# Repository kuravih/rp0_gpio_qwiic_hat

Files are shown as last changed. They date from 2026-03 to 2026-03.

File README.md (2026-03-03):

# Raspberry Pi qwiic hat

Raspberry pi GPIO pins can can be configured as i<sup>2</sup>c as described [here][1].
There are 28 GPIO pins which can be configured as 14 i<sup>2</sup>c buses in total.
This hat wires these 14 i<sup>2</sup>c busses including the [5 V rail][3] and the ground to 14 [qwiic][2] connectors.
Add the following to the `[all]` section of the `/boot/firmware/config.txt` file to enable the i<sup>2</sup>c busses.
The i<sup>2</sup>c devices will be available at `dev/i2c-n` (where n will be the bus number used in the dtoverlay).
This setup along with ~100 [ds28ea00_sensorlets][4] were flown on PICTURE-C flight in 2025 to continuously monitor the instrument temperature at numerous locations.

    dtoverlay=i2c-gpio,i2c_gpio_sda=27,i2c_gpio_scl=18,bus=10
    dtoverlay=i2c-gpio,i2c_gpio_sda=25,i2c_gpio_scl=9,bus=11
    dtoverlay=i2c-gpio,i2c_gpio_sda=5,i2c_gpio_scl=11,bus=12
    dtoverlay=i2c-gpio,i2c_gpio_sda=12,i2c_gpio_scl=6,bus=13
    dtoverlay=i2c-gpio,i2c_gpio_sda=19,i2c_gpio_scl=26,bus=14
    dtoverlay=i2c-gpio,i2c_gpio_sda=15,i2c_gpio_scl=17,bus=15
    dtoverlay=i2c-gpio,i2c_gpio_sda=23,i2c_gpio_scl=22,bus=16
    dtoverlay=i2c-gpio,i2c_gpio_sda=10,i2c_gpio_scl=24,bus=17
    dtoverlay=i2c-gpio,i2c_gpio_sda=1,i2c_gpio_scl=0,bus=18
    dtoverlay=i2c-gpio,i2c_gpio_sda=2,i2c_gpio_scl=3,bus=19
    dtoverlay=i2c-gpio,i2c_gpio_sda=4,i2c_gpio_scl=14,bus=20
    dtoverlay=i2c-gpio,i2c_gpio_sda=7,i2c_gpio_scl=8,bus=21
    dtoverlay=i2c-gpio,i2c_gpio_sda=20,i2c_gpio_scl=21,bus=22
    dtoverlay=i2c-gpio,i2c_gpio_sda=16,i2c_gpio_scl=13,bus=23

## Schematic
<p align="center">
  Schematic
</p>

## PCB

<p align="center">
  PCB
</p>

## Photos

<p align="center">
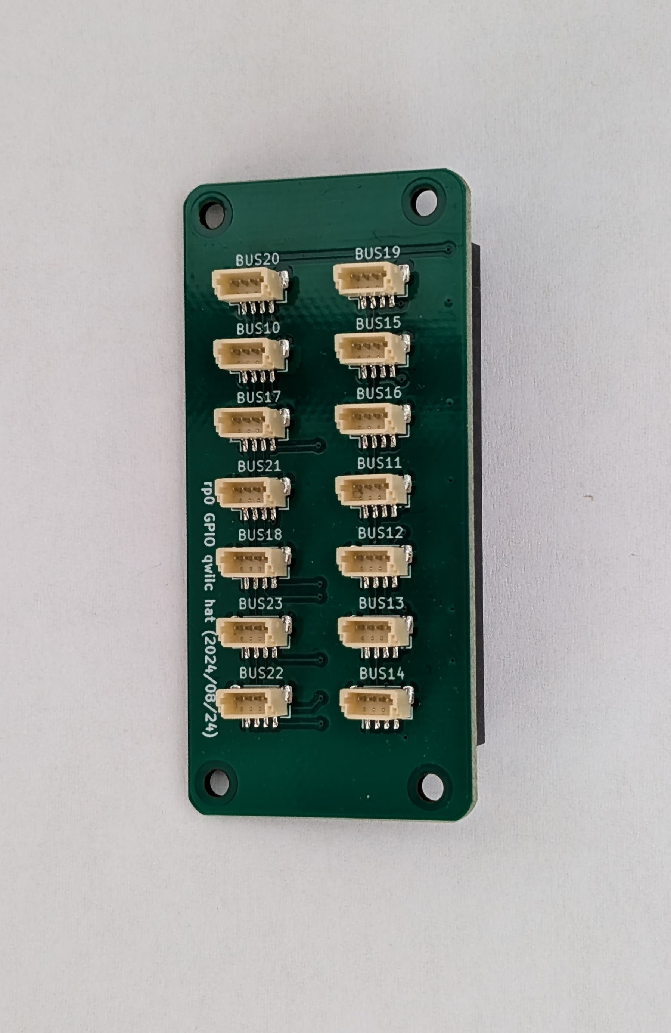
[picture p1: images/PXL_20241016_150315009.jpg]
Front
  
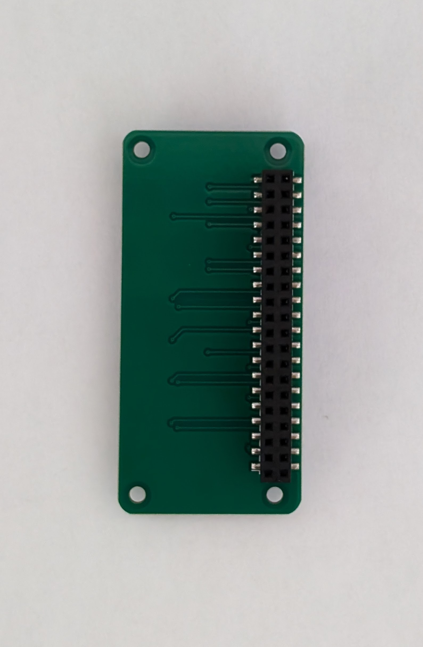
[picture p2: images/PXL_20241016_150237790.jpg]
Back
  
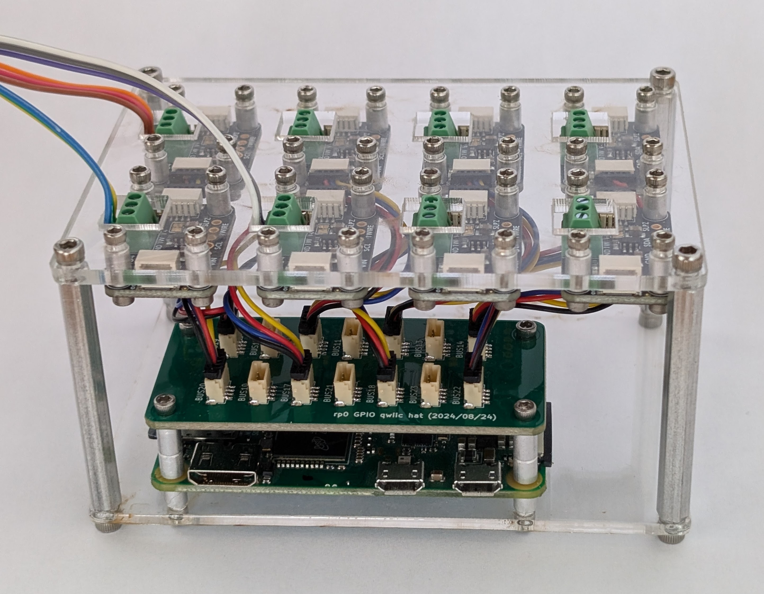
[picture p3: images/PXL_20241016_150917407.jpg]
Usage
  
</p>

[1]: https://forums.raspberrypi.com/viewtopic.php?t=205576
[2]: https://www.sparkfun.com/qwiic
[3]: https://pinout.xyz/pinout/5v_power 
[4]: https://github.com/kuravih/ds28ea00_sensorlet

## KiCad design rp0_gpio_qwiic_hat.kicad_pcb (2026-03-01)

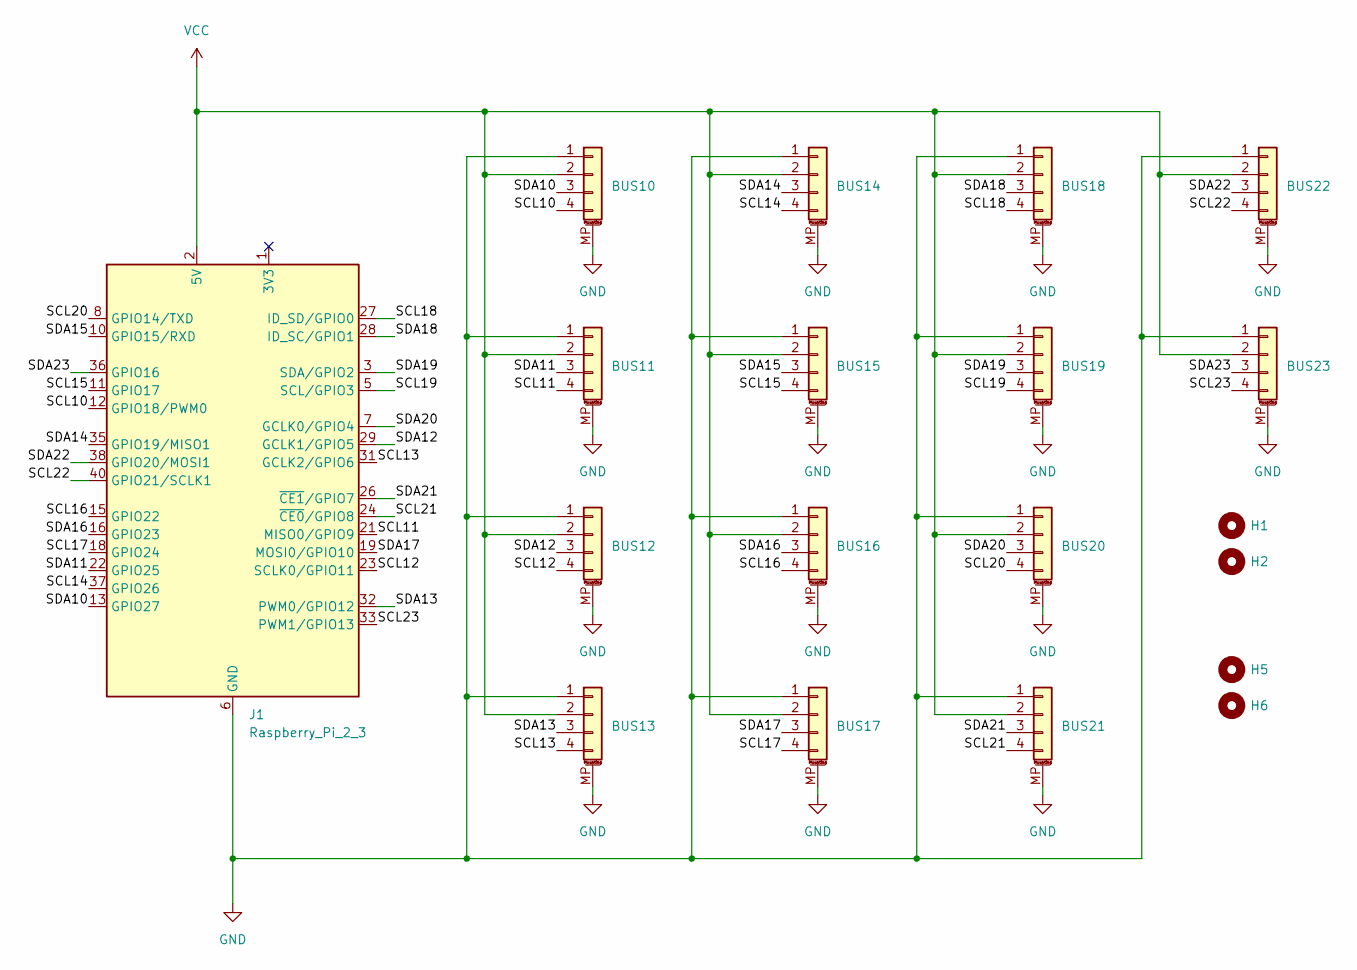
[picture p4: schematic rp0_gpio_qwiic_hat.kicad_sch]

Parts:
BUS10, BUS11, BUS12, BUS13, BUS14, BUS15, BUS16, BUS17, BUS18, BUS19, BUS20, BUS21, BUS22, BUS23: Conn_01x04_MountingPin; JST_SH_BM04B-SRSS-TB_1x04-1MP_P1.00mm_Vertical; JLCPCB Part # C160390
H1, H2, H5, H6: MountingHole; MountingHole_2.7mm_M2.5
J1: Raspberry_Pi_2_3; PinSocket_2x20_P2.54mm_Vertical_SMD; JLCPCB Part # C3975165

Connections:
/SCL10: BUS10.4, J1.12 (GPIO18/PWM0)
/SCL11: BUS11.4, J1.21 (MISO0/GPIO9)
/SCL12: BUS12.4, J1.23 (SCLK0/GPIO11)
/SCL13: BUS13.4, J1.31 (GCLK2/GPIO6)
/SCL14: BUS14.4, J1.37 (GPIO26)
/SCL15: BUS15.4, J1.11 (GPIO17)
/SCL16: BUS16.4, J1.15 (GPIO22)
/SCL17: BUS17.4, J1.18 (GPIO24)
/SCL18: BUS18.4, J1.27 (ID_SD/GPIO0)
/SCL19: BUS19.4, J1.5 (SCL/GPIO3)
/SCL20: BUS20.4, J1.8 (GPIO14/TXD)
/SCL21: BUS21.4, J1.24 (~CE0/GPIO8)
/SCL22: BUS22.4, J1.40 (GPIO21/SCLK1)
/SCL23: BUS23.4, J1.33 (PWM1/GPIO13)
/SDA10: BUS10.3, J1.13 (GPIO27)
/SDA11: BUS11.3, J1.22 (GPIO25)
/SDA12: BUS12.3, J1.29 (GCLK1/GPIO5)
/SDA13: BUS13.3, J1.32 (PWM0/GPIO12)
/SDA14: BUS14.3, J1.35 (GPIO19/MISO1)
/SDA15: BUS15.3, J1.10 (GPIO15/RXD)
/SDA16: BUS16.3, J1.16 (GPIO23)
/SDA17: BUS17.3, J1.19 (MOSI0/GPIO10)
/SDA18: BUS18.3, J1.28 (ID_SC/GPIO1)
/SDA19: BUS19.3, J1.3 (SDA/GPIO2)
/SDA20: BUS20.3, J1.7 (GCLK0/GPIO4)
/SDA21: BUS21.3, J1.26 (~CE1/GPIO7)
/SDA22: BUS22.3, J1.38 (GPIO20/MOSI1)
/SDA23: BUS23.3, J1.36 (GPIO16)
GND: BUS10.1, BUS10.MP (MountPin), BUS11.1, BUS11.MP (MountPin), BUS12.1, BUS12.MP (MountPin), BUS13.1, BUS13.MP (MountPin), BUS14.1, BUS14.MP (MountPin), BUS15.1, BUS15.MP (MountPin), BUS16.1, BUS16.MP (MountPin), BUS17.1, BUS17.MP (MountPin), BUS18.1, BUS18.MP (MountPin), BUS19.1, BUS19.MP (MountPin), BUS20.1, BUS20.MP (MountPin), BUS21.1, BUS21.MP (MountPin), BUS22.1, BUS22.MP (MountPin), BUS23.1, BUS23.MP (MountPin), J1.6 (GND), J1.9 (GND), J1.14 (GND), J1.20 (GND), J1.25 (GND), J1.30 (GND), J1.34 (GND), J1.39 (GND)
VCC: BUS10.2, BUS11.2, BUS12.2, BUS13.2, BUS14.2, BUS15.2, BUS16.2, BUS17.2, BUS18.2, BUS19.2, BUS20.2, BUS21.2, BUS22.2, BUS23.2, J1.2 (5V), J1.4 (5V)

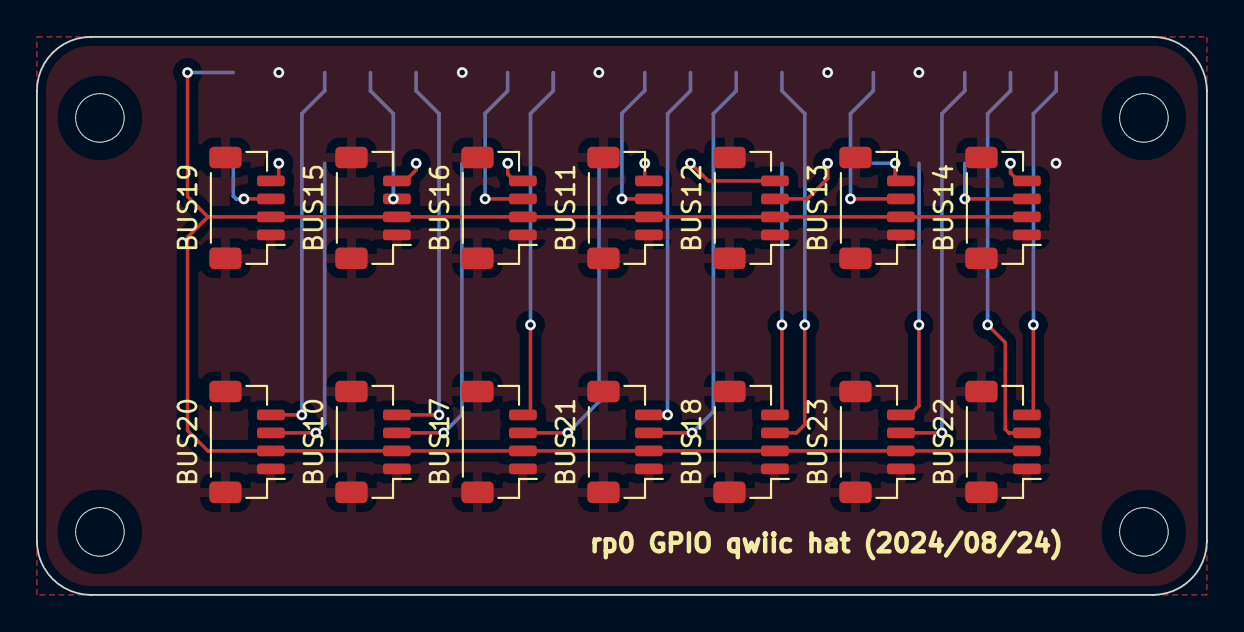
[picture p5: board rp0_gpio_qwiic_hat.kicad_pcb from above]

Board: 2 copper layers, 65.0 x 31.0 mm, 19 parts (1 on the bottom side), 30 nets.
